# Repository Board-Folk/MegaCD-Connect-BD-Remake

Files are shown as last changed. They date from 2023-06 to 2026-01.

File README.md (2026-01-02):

# MegaCD-Connect-BD-Remake
This is the Schematics, PCB and Logic for the Mega-CD Connect BD Targeting the 315-5477 (MCE V1) MegaCD.

It is to replace the 837-8327-01 IC BD MEGA-CD CONNECT BD with a failed ASIC to the older Logic version of the board that has the Peel IC.

The board is not a clone, rather a remake as i do not have access to an original logic board version to do an exact replica of traces.

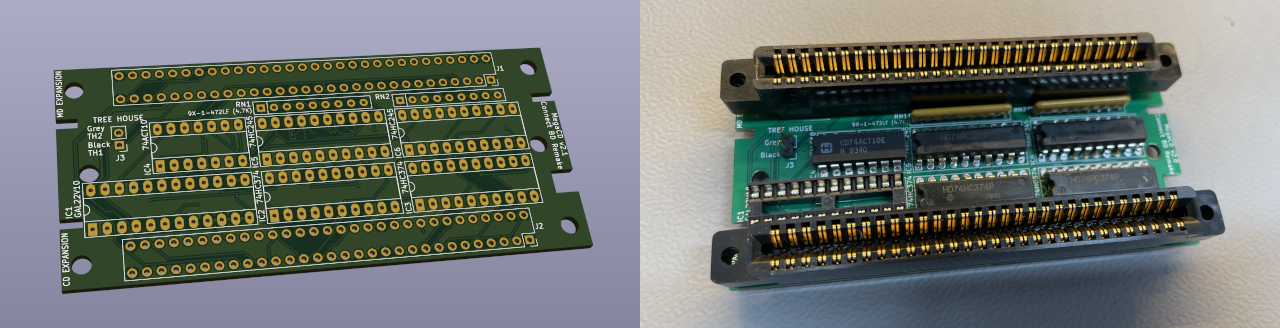
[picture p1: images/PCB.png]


* The Gerbers have been created using the recommendations from JLCPCB.

* This board uses a GAL22V10 to achieve the same logic functions as the Peel IC. Jed file is provided.
  Use a MiniPro to write the Jed file to the GAL Chip.

Notes:- 

 * I have used an ATF22V10B-15PC as a replacement for the GAL22V10. The ATF Works, but i also see this is obsolete. There is ATF22V10C range of chips, but stock seems to be low on these.

 * TESTED V2.0 and this worked, but now made V2.2 and is UNTESTED
   
 * Finally got some GAL20v8 Chips, and they do not work. Think this is a timing issue. So please use the GAL22v10's instead, unless someone wants to take a stab at getting the GAL20v8's to work. (Looks at Steve)

Version 2.3 Changes:-

Updates to Kicad v9, Changed A26/B26 on the CD Expansion to point to 9v, and not 5v. Made no difference with the older version, but made it now match the original PCB.

Added new Logic version, because GALasm was updated and was giving a different compiled version that does not work. Found what i needed to change to make it work.

You can use either Pre-Compiled Jed Files, for the GAL22v10 / ATF22V10

Version 2.2 Changes:-

* Moved traces around the middle screw holes, just incase screw heads sub against the silkscreen removing it and causing a short against the 5v rail.

* Moved the IC1 Silk name slightly up.

Version 2.1 Changes:-

* Moved /TRDIR from PIN 23 to PIN 15, This should make it compatible with the GAL20V8

* Added GAL20V8 Logic, but does not work.

* Updated Labels for Tree House Connection, TH1 and TH2

### Compiling The Logic
---

The software i used to make the Jed file was GALasm. It can be downloaded from here https://github.com/daveho/GALasm

Only source files is provide, so you will need to compile GALasm first. I used MacOS to do this, Linux should work and maybe Windows ???

Once GALasm is compiled, use the following command to compile the Logic into a Jed file from within the GAL22V10 folder.

```
galasm ./GAL22V10.pld
```

### Fitting the Board
---

**1. Post**

---

There is a slight modification required to make the PCB fit in the original housing.

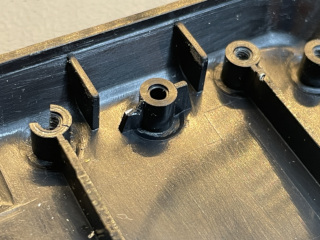
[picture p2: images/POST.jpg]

<br>This Post would need a little snip to allow the GAL chip pins to sit correctly in the housing.

**2. Tree House J3**

---

If you use a Pin Header, you will need to bend it slighly inwards otherwise it will not fit inside the MegaCD.

### BOM

---

| Reference | Value | Quantity | DigiKey | Mouser |
|---|---|---|---|---|
| C1 - C6 | 100nf | 6 | CL31B104KBCNNNC | 187-CL31B104KBCNNNC  |
| IC1 | GAL22V10B-15 / ATF22V10B-15 | 1 | | 556-AF22V10C15PU |
| IC2, IC3  | 74HC374 | 2 | 296-1592-5-ND | 595-SN74HC374N |
| IC4 | 74ACT10 | 1 | CD74ACT10E-ND | 595-CD74ACT10E |
| IC5, IC6  | 74HC245 | 2 | 296-1584-5-ND | 595-SN74HC245N |
| RN1, RN2  | 9X-1-472LF (4.7K) | 2 | 4609X-101-472LF-ND | 652-4609X-1LF-4.7K |
| J1, J2 | CONN EDGE DF 60POS | 2 | A112392-ND | 571-1-5530841-8 |
| J3 | 2 Pin Header 2.54mm | 1 | 609-4434-ND | 649-77311-118-02LF |

[**Interactive BOM**][IBOM]

## Thanks

With thanks to @fabiodl for decoding the logic of the Peel IC

* https://github.com/fabiodl/peelDecoder

#### Other Resources

* https://circuit-board.de/forum/index.php/Thread/25582-SEGA-MEGA-CD-1-Reparatur-PEEL-18CV8-PLD-auslesen/

* https://www.eevblog.com/forum/projects/help-with-reverse-engineering-unexpected-behavior-of-peel18cv8-223204/

### !!!!! WARNING !!!!!

Use at your own risk. I accept no responsibility.

[IBOM]: http://htmlpreview.github.io/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

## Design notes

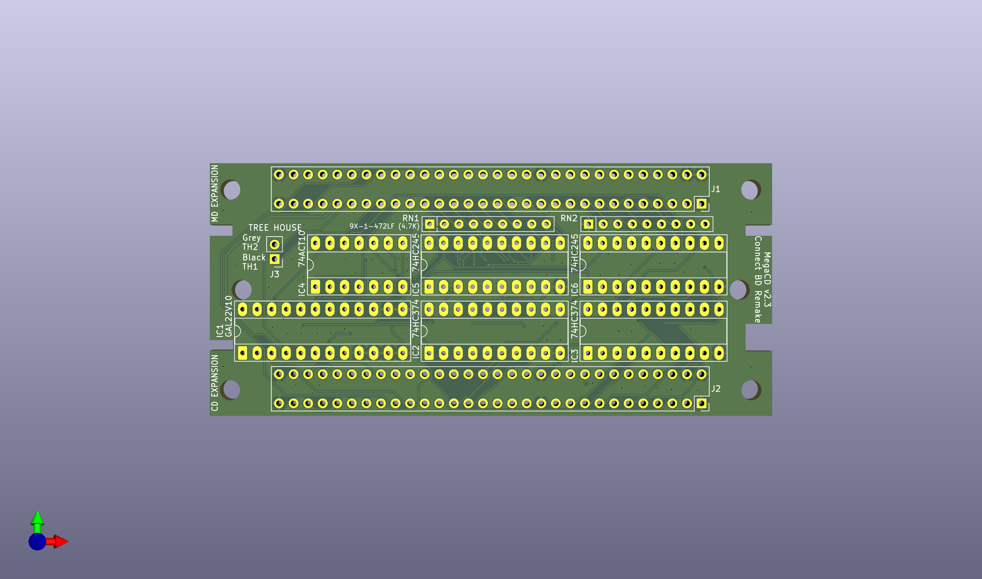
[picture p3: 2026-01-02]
MegaCD-Connect BD Remake.png

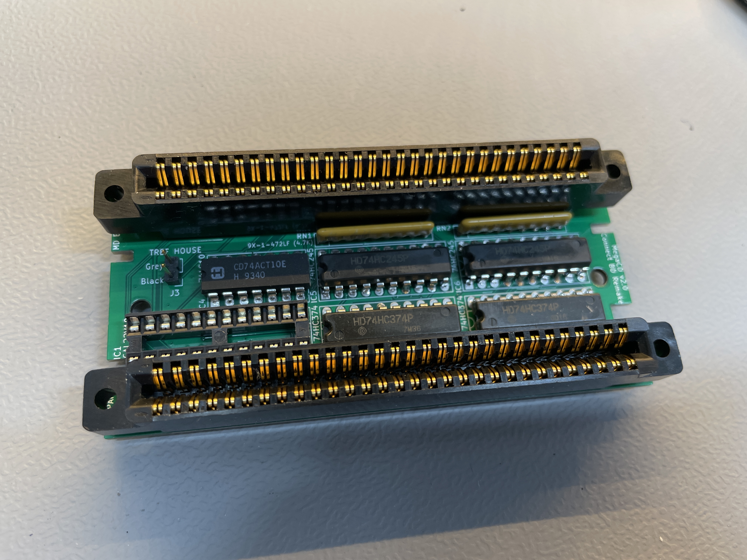
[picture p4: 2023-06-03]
images/MAIN.jpg

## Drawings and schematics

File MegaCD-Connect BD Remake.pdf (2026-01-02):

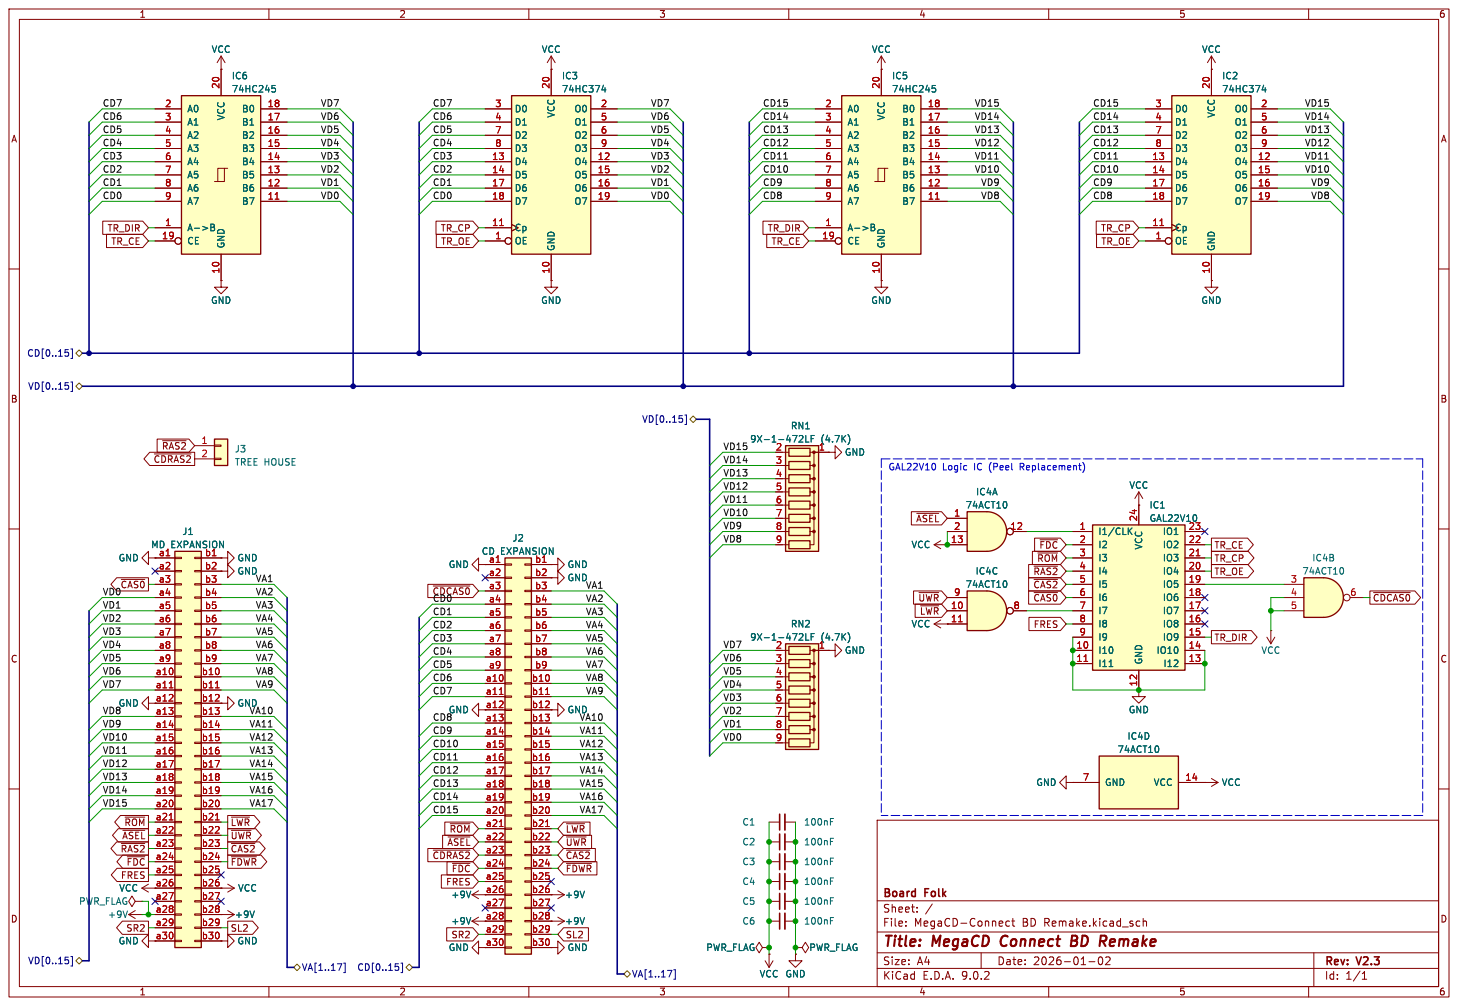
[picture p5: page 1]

Id: 1/1 Title: MegaCD Connect BD Remake

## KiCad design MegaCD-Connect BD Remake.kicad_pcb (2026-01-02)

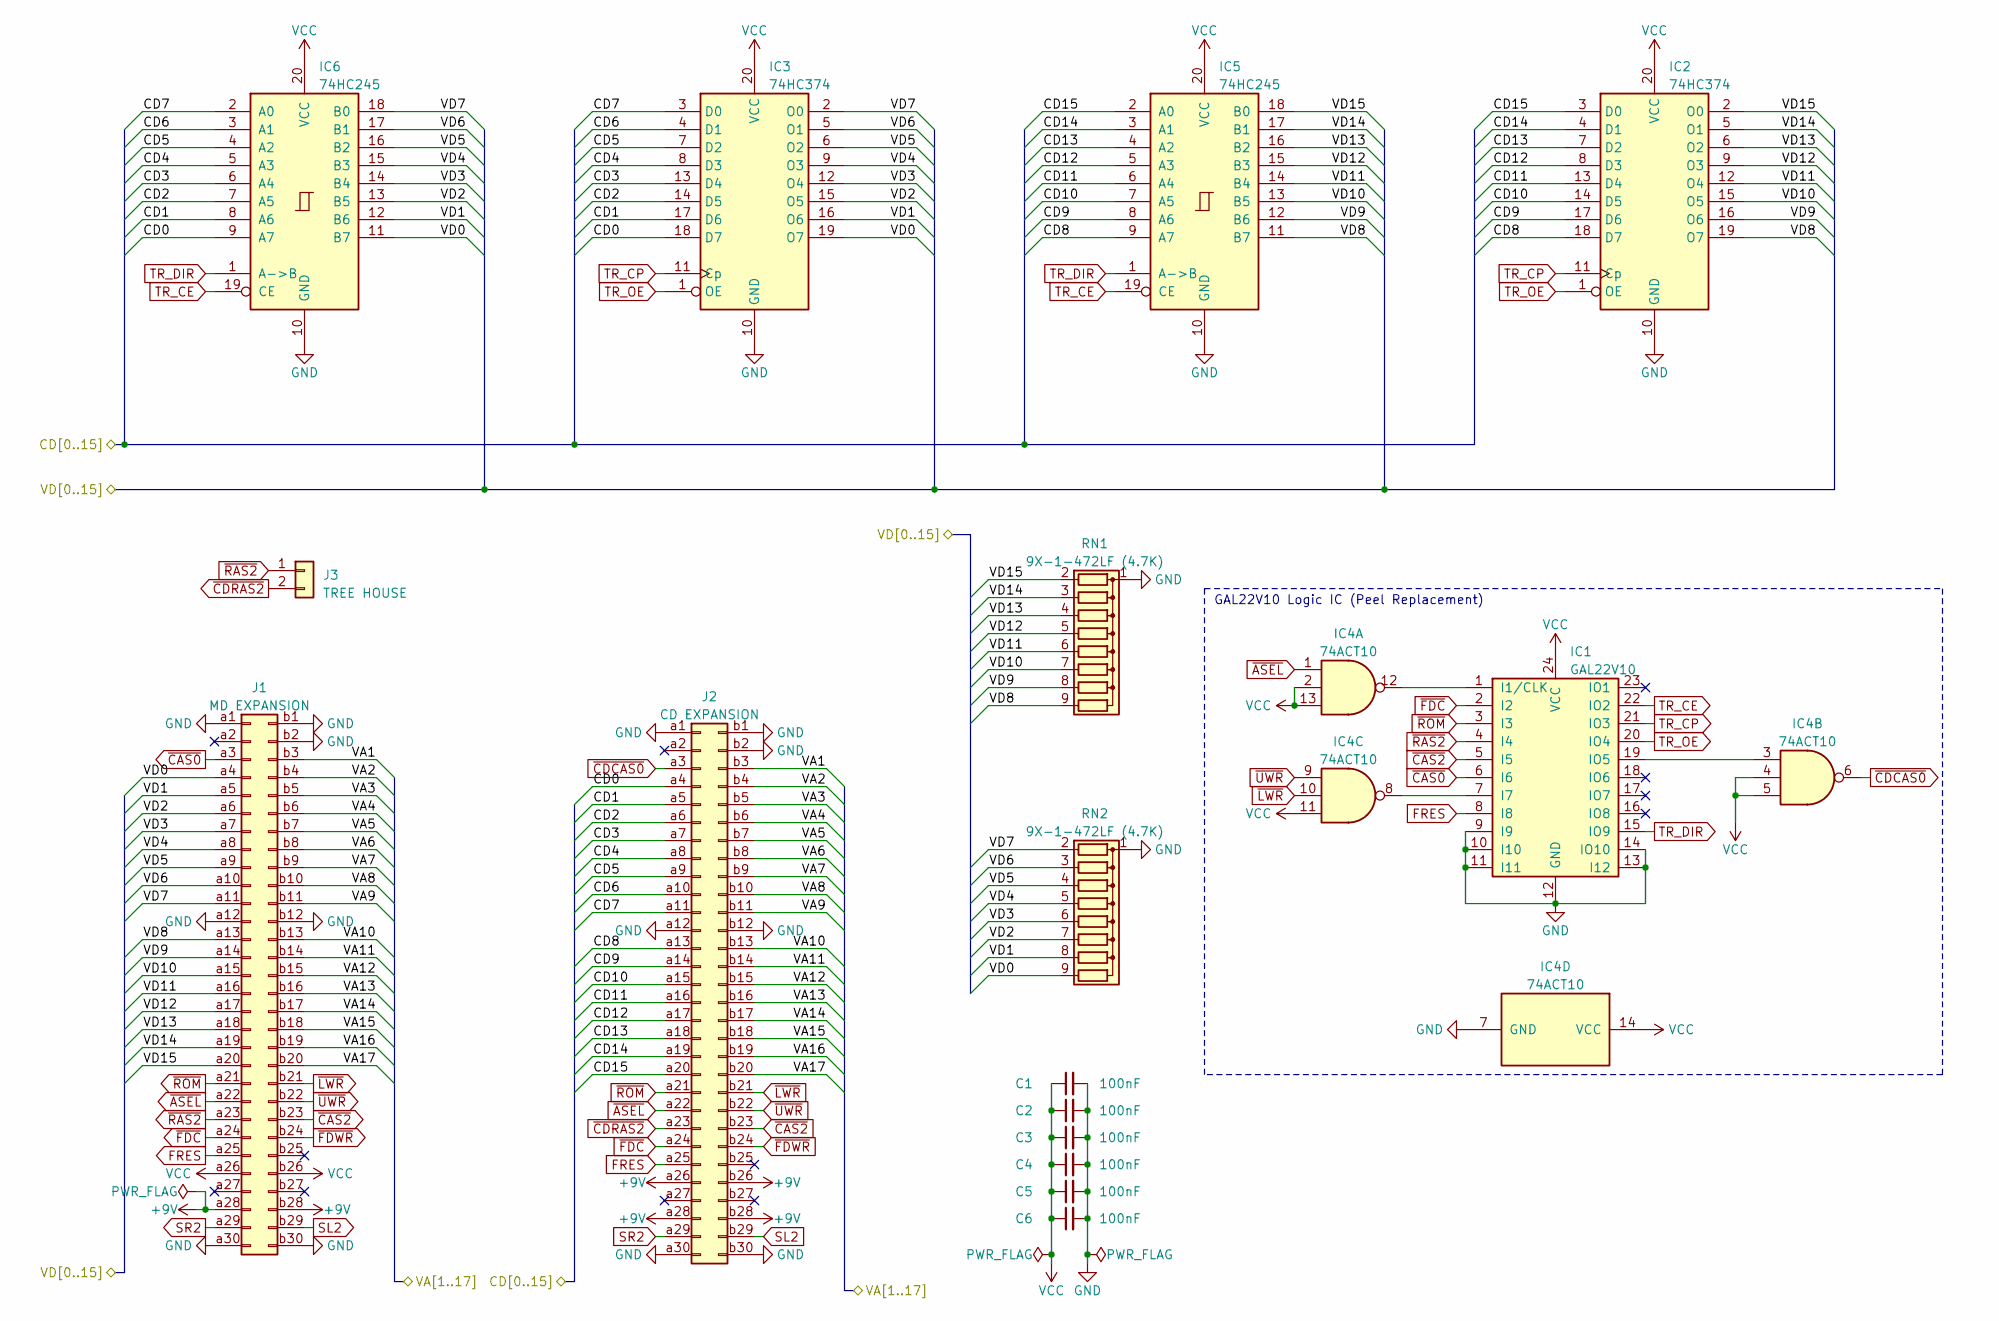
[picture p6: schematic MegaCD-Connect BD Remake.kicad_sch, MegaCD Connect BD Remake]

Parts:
C1, C2, C3, C4, C5, C6: 100nF; C_1206_3216Metric
IC1: GAL22V10; DIP-24_W7.62mm_Socket_LongPads
IC2, IC3: 74HC374; DIP-20_W7.62mm_Socket_LongPads
IC4: 74ACT10; DIP-14_W7.62mm_Socket_LongPads
IC5, IC6: 74HC245; DIP-20_W7.62mm_Socket_LongPads
J1: MD EXPANSION; PCB-Connector
J2: CD EXPANSION; PCB-Connector
J3: TREE HOUSE; PinHeader_1x02_P2.54mm_Vertical
RN1, RN2: 9X-1-472LF (4.7K); R_Array_SIP9

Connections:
+9V: J1.a28, J1.b28, J2.a26, J2.a28, J2.b26, J2.b28
/CD0: IC3.18 (D7), IC6.9 (A7), J2.a4
/CD1: IC3.17 (D6), IC6.8 (A6), J2.a5
/CD2: IC3.14 (D5), IC6.7 (A5), J2.a6
/CD3: IC3.13 (D4), IC6.6 (A4), J2.a7
/CD4: IC3.8 (D3), IC6.5 (A3), J2.a8
/CD5: IC3.7 (D2), IC6.4 (A2), J2.a9
/CD6: IC3.4 (D1), IC6.3 (A1), J2.a10
/CD7: IC3.3 (D0), IC6.2 (A0), J2.a11
/CD8: IC2.18 (D7), IC5.9 (A7), J2.a13
/CD9: IC2.17 (D6), IC5.8 (A6), J2.a14
/CD10: IC2.14 (D5), IC5.7 (A5), J2.a15
/CD11: IC2.13 (D4), IC5.6 (A4), J2.a16
/CD12: IC2.8 (D3), IC5.5 (A3), J2.a17
/CD13: IC2.7 (D2), IC5.4 (A2), J2.a18
/CD14: IC2.4 (D1), IC5.3 (A1), J2.a19
/CD15: IC2.3 (D0), IC5.2 (A0), J2.a20
/VA1: J1.b3, J2.b3
/VA2: J1.b4, J2.b4
/VA3: J1.b5, J2.b5
/VA4: J1.b6, J2.b6
/VA5: J1.b7, J2.b7
/VA6: J1.b8, J2.b8
/VA7: J1.b9, J2.b9
/VA8: J1.b10, J2.b10
/VA9: J1.b11, J2.b11
/VA10: J1.b13, J2.b13
/VA11: J1.b14, J2.b14
/VA12: J1.b15, J2.b15
/VA13: J1.b16, J2.b16
/VA14: J1.b17, J2.b17
/VA15: J1.b18, J2.b18
/VA16: J1.b19, J2.b19
/VA17: J1.b20, J2.b20
/VD0: IC3.19 (O7), IC6.11 (B7), J1.a4, RN2.9 (R8)
/VD1: IC3.16 (O6), IC6.12 (B6), J1.a5, RN2.8 (R7)
/VD2: IC3.15 (O5), IC6.13 (B5), J1.a6, RN2.7 (R6)
/VD3: IC3.12 (O4), IC6.14 (B4), J1.a7, RN2.6 (R5)
/VD4: IC3.9 (O3), IC6.15 (B3), J1.a8, RN2.5 (R4)
/VD5: IC3.6 (O2), IC6.16 (B2), J1.a9, RN2.4 (R3)
/VD6: IC3.5 (O1), IC6.17 (B1), J1.a10, RN2.3 (R2)
/VD7: IC3.2 (O0), IC6.18 (B0), J1.a11, RN2.2 (R1)
/VD8: IC2.19 (O7), IC5.11 (B7), J1.a13, RN1.9 (R8)
/VD9: IC2.16 (O6), IC5.12 (B6), J1.a14, RN1.8 (R7)
/VD10: IC2.15 (O5), IC5.13 (B5), J1.a15, RN1.7 (R6)
/VD11: IC2.12 (O4), IC5.14 (B4), J1.a16, RN1.6 (R5)
/VD12: IC2.9 (O3), IC5.15 (B3), J1.a17, RN1.5 (R4)
/VD13: IC2.6 (O2), IC5.16 (B2), J1.a18, RN1.4 (R3)
/VD14: IC2.5 (O1), IC5.17 (B1), J1.a19, RN1.3 (R2)
/VD15: IC2.2 (O0), IC5.18 (B0), J1.a20, RN1.2 (R1)
FRES: IC1.8 (I8), J1.a25, J2.a25
GND: C1.2, C2.2, C3.2, C4.2, C5.2, C6.2, IC1.9 (I9), IC1.10 (I10), IC1.11 (I11), IC1.12 (GND), IC1.13 (I12), IC1.14 (IO10), IC2.10 (GND), IC3.10 (GND), IC4.7 (GND), IC5.10 (GND), IC6.10 (GND), J1.a1, J1.a12, J1.a30, J1.b1, J1.b2, J1.b12, J1.b30, J2.a1, J2.a12, J2.a30, J2.b1, J2.b2, J2.b12, J2.b30, RN1.1 (common), RN2.1 (common)
unnamed: IC1.1 (I1/CLK), IC4.12
unnamed: IC1.7 (I7), IC4.8
unnamed: IC1.19 (IO5), IC4.3
SL2: J1.b29, J2.b29
SR2: J1.a29, J2.a29
TR_CE: IC1.22 (IO2), IC5.19 (CE), IC6.19 (CE)
TR_CP: IC1.21 (IO3), IC2.11 (Cp), IC3.11 (Cp)
TR_DIR: IC1.15 (IO9), IC5.1 (A->B), IC6.1 (A->B)
TR_OE: IC1.20 (IO4), IC2.1 (OE), IC3.1 (OE)
VCC: C1.1, C2.1, C3.1, C4.1, C5.1, C6.1, IC1.24 (VCC), IC2.20 (VCC), IC3.20 (VCC), IC4.2, IC4.4, IC4.5, IC4.11, IC4.13, IC4.14 (VCC), IC5.20 (VCC), IC6.20 (VCC), J1.a26, J1.b26
~ASEL: IC4.1, J1.a22, J2.a22
~CAS0: IC1.6 (I6), J1.a3
~CAS2: IC1.5 (I5), J1.b23, J2.b23
~CDCAS0: IC4.6, J2.a3
~CDRAS2: J2.a23, J3.2
~FDC: IC1.2 (I2), J1.a24, J2.a24
~FDWR: J1.b24, J2.b24
~LWR: IC4.10, J1.b21, J2.b21
~RAS2: IC1.4 (I4), J1.a23, J3.1
~ROM: IC1.3 (I3), J1.a21, J2.a21
~UWR: IC4.9, J1.b22, J2.b22

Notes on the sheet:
GAL22V10 Logic IC (Peel Replacement)

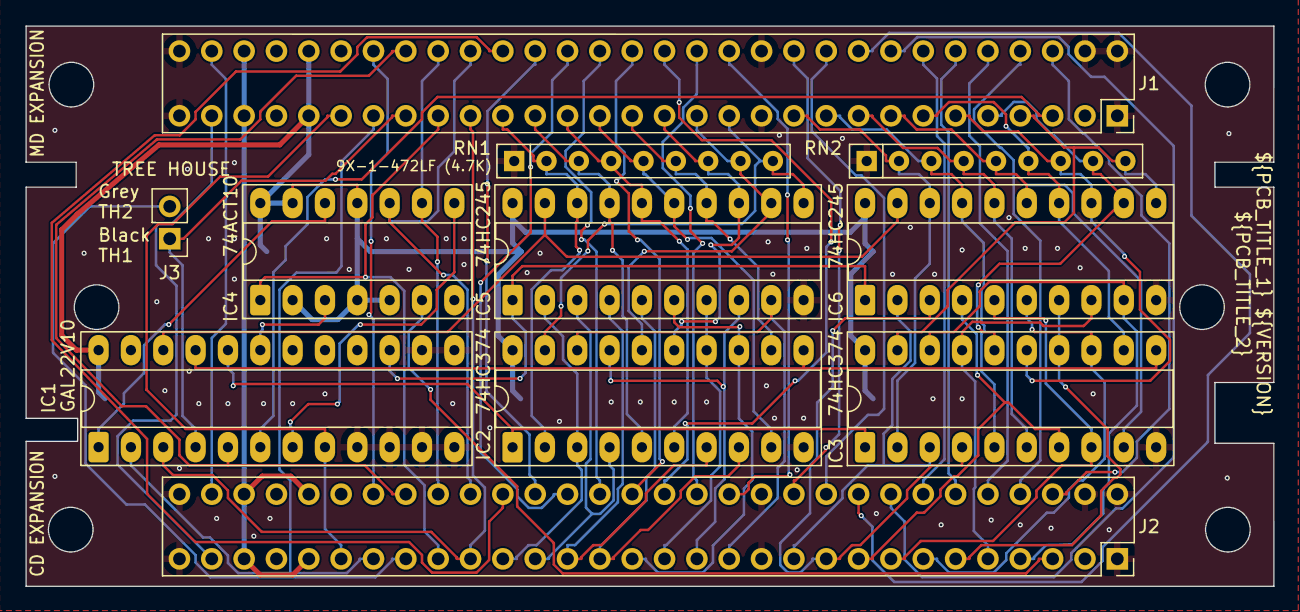
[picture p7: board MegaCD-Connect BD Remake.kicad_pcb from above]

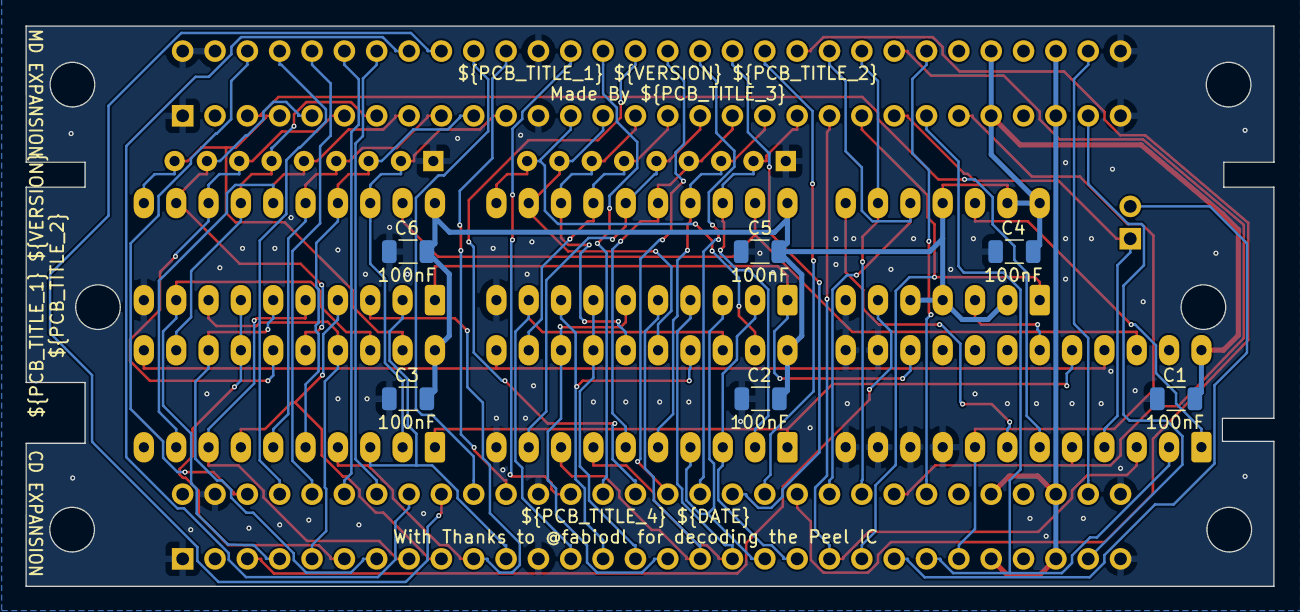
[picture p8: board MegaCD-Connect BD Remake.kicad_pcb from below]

Board: 2 copper layers, 98.0 x 44.0 mm, 17 parts (6 on the bottom side), 73 nets.

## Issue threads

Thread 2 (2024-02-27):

Issue programming the GAL

Parakas82, 2024-02-27:
Hi there,

Thanks for your projects, I am big fan! I am trying to reconstruct two JAP MCD1 units that had really bad PCBs, and they are coming back to life thanks to you.

Unfortunately I got stuck in the last bit, programming the GALs.
I got some (5X) GAL22V10B-15PC, and I am trying to program them with my T48 programmer, I load the JED file , and everything seems in order, but I get the following error when I try:

APP Version : 12.66   Model : T48
     Device : GAL22V10B
Pins Detected Passed!
Erase Chip....Timer : 828ms
Programing Fuse Bits completed ....Timer :4750 ms
Verify Error!    FUSE bit:0     Buff_val: 0     IC_val: 1
Programming Stopped!

And then I see that the GAL has only 1´s in it, so the process did nothing in the end.

I have tried different VPP voltages, enabling and disabling the ¨Encrypt Chip¨ flag, different IC models.... I run out of ideas to be honest. Apologies in advance if this is not the right place to ask something like this, I am not familiar using GitHub.
Thank you in advance for your time,

Regards.

chris-jh, 2024-02-27:
Where did you get the GAL's from ?

Parakas82, 2024-02-27:
Hi, Aliexpress 🙃 Got any good recommendation where should I source them at a reasonable price?

Thanks for the help!

chris-jh, 2024-02-27:
ah, yeah will be hit or miss with Ali, i had some that worked fine and others programmed no errors. But didn't worked.

Ones i got from eBay also worked, but probably same in getting genuine or fakes.

The mouser ATF22V10C-15PU as an alternative, at least with them should be real.

or try your luck on Ali/Ebay maybe they don't fake them as much ?? 😂

BBZ149, 2024-02-27:
Hi Chris, would pic of attached GAL work OK?

Thanks
Terry
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

chris-jh, 2024-02-28:
Looks ok, but looks can be deceiving😄, try it and see.

It will either programme and work, or programme and black screen, or not programme.

BBZ149, 2024-02-28:
That's true! lol but going by the model of the Chip is that the correct one? As I have to buy 15 and not cheap 😞 But they are 100% genuine!

chris-jh, 2024-02-29:
I am unsure i have only used the chips marked as GAL22V10B-15LP or ATF22V10B-15PC.

Parakas82, 2024-03-01:
Hi Chris,

Following your advice, I got some ATF22V10C-15PU on their way:
https://www.rs-online-privat.de/Products/ProductDetail/Microchip-SPLD-Simple-Programmable-Logic-Device-ATF22V10C-350-Gates-10-Makrozellen-10-I-O-83-3MHz-15ns-CMOS-TT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

Hopefully they will do the job, thanks for the help!

Regards.

chris-jh, 2024-03-24:
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

Did they work ?

Parakas82, 2024-03-24:
Hey Chris,

Experienced a bit of a nightmare with the delivery, but got them finally: they erased/programmed straight away. They are on their way to my colleague via post, to be tested with my two MCDs to be resurrected :) I'll let you know how it went.

Regards.

LobAnovich, 2024-03-26:
Greetings !  If using ATF22V10B-15PC, should I use the .jed firmware file from GAL22V10?

chris-jh, 2024-03-27:
yeah use the GAL22V10 jed as the ATF22V10B in the minipro if you are using that to program

Parakas82, 2024-03-30:
Confirmed, they work!!

LobAnovich, 2024-04-30:
Greetings !  I received 2 + 2 GAL22V10B chips from Ali from different sellers.  The chips are erased, programmed, but do not pass verification unless the “verification after recording” checkbox is unchecked.  Is it possible that this is a “lock bit” action and for the same reason it is impossible to remove a dump from the original chip or are these still fake chips?  Do I need to leave the “lock bit” and “encrypt chip” checkboxes before recording?  Programmer TL866II-Plus.  Xgpro 12.66 program

Closed 2024-03-30.

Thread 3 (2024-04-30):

GAL & ATF programming

LobAnovich, 2024-04-30:
Greetings !  I received 2 + 2 GAL22V10B chips from Ali from different sellers.  The chips are erased, programmed, but do not pass verification unless the “verification after recording” checkbox is unchecked.  Is it possible that this is a “lock bit” action and for the same reason it is impossible to remove a dump from the original chip or are these still fake chips?  Do I need to leave the “lock bit” and “encrypt chip” checkboxes before recording?  Programmer TL866II-Plus.  Xgpro 12.66 program

The situation with programming the ATF22V10C is slightly different.  The chips are erased, programmed, and verified at the end of the programming process, but if you try to re-verify separately, the verification is immediately loaded with exactly the same error as in the case of GAL during the programming process.  This gave me the idea that this situation arose due to the operation of the “lock bit”.  Or are all the chips faulty?

chris-jh, 2024-04-30:
Have you tried them yet?

I can't remember getting verification errors and i didnt mess with any lock bits or encryption.

years ago go i did use the gui version, but Mac is my main os and i use the open source minipro command line version now and i never specified them options.

If they dont work in the board, then i would assume fake or faulty.

unless it is the minipro you have ? an original or a clone ? i bought mine direct from xgecu

LobAnovich, 2024-04-30:
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

I have the original Xgecu TL866II-Plus programmer, which I have been using for many years.  I just identified a completely faulty batch of logic 74374 with his help, which I bought for assembling a riser board.  Lots 7410 and 74245 are fully operational

LobAnovich, 2024-04-30:
As I wrote earlier, the Chinese sent ATF22V10CQZ-20PC chips instead of ATF22V10B-15PC.  After several checks, I was able to write, count, and check a randomly selected chip, like ATF22V10C, several times, with a write voltage of 12 Volts and with the “lockbit” checkbox unchecked before writing

LobAnovich, 2024-05-05:
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

I restored my Sega mega cd addon and checked the adapter board clone.  I haven't tested it for a long time, so far it works fine

LobAnovich, 2024-12-14:
Also, all different ATF22V10B chips from different sellers, which were normally programmed and verified, do not work normally in sonic cd. The picture in the game itself, crumbles into squares, and then the game freezes. Only one version of GAL22V10B chips, from a large number that I bought from different sellers and which were normally flashed, has no problems in operation.

chris-jh, 2024-12-14:
What logic chips you are using ? i had issues with IC4 thinking it was something with the GAL Code. But it was that chip, which tested good in logic tests. But it was wrong/fake from the seller. Swapped that chip from ones i bought from mouser all good. it delayed this project a year. Shakes fists at fake chip sellers....

chris-jh, 2024-12-14:
Basically the Logic Chips needs to be the types specified on the BOM IC4 needs to be an ACT

LobAnovich, 2024-12-14:
ATF22V10B-15PC. ATF22V10CQZ-20PU
These are the chips that are flashed and verified normally. The project works with these chips, but the gameplay of the sonic cd does not work correctly.

LobAnovich, 2024-12-14:
Although... I reflashed the original IC4 with a multi-regional BIOS and there were much fewer artifacts with the ATF22V10B-15PC. I even managed to pass the first level. The second level started without any artifacts at all. It is quite possible that my ATF22V10B-15PC are actually relabeled from slower ATF22V10B-20,25 or even slower ones. As an experiment, I will try to find a faster chip for IC4 (-70 or -10). Finding a real working GAL22 or ATF22 is a very big problem.

LobAnovich, 2024-12-14:
> What logic chips you are using ? i had issues with IC4 thinking it was something with the GAL Code. But it was that chip, which tested good in logic tests. But it was wrong/fake from the seller. Swapped that chip from ones i bought from mouser all good. it delayed this project a year. Shakes fists at fake chip sellers....

What IC4 are you talking about? The logic chip on the connector board? I assumed that you were writing about the IC4 on the main board. And I replaced the BIOS chip with the original one reflashed with a multibios))) Although this also gave a result. A very positive result.
As for the IC4 on the connector board, I have 74HC10 installed, but there is also 74ACT10. Both versions pass tests on the programmer. I can also try replacing HC with ACT

chris-jh, 2024-12-14:
IC4 on the connect-bd board. I know the original peel board has all HC, and i can't remember why i put ACT in the box now. But i was getting lots of corruption and things, when this IC was not correct.

Other thing, did you put them caps back on the back of your board also ? Sega, being sega used to like adjusting timings by adding caps it seems. Was wondering if the boards you are trying are on this megacd that had them extra caps ?

chris-jh, 2024-12-14:
I bought the ATF22V10C15PU from mouser (556-AF22V10C15PU) they have plenty of stock and not EOL as far as i know. These are what i used.

Someone also pointed out to me that the ATF22V10 have a problem. The last fuse enables a "power down" mode on pin 4, and if it is erased it defaults to on. If you don't have a programmer that knows this you get odd behaviour when power down mode goes on.

LobAnovich, 2024-12-14:
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

I installed ceramic capacitors for regulation, like on the original board I had.

chris-jh, 2024-12-14:
wonder what happens with them removed between the resistor arrays.

Like i said, Sega when it sees issues with certain machines, they like to tweak data lines manually by adding random caps 😂

LobAnovich, 2024-12-14:
> wonder what happens with them removed between the resistor arrays.
>
> Like i said, Sega when it sees issues with certain machines, they like to tweak data lines manually by adding random caps 😂

I agree, but they do the adjustment manually not on each individual copy or even a separate batch, but on the entire batch, which was assembled from certain, identical components. That is, if, let's say, they started using any chip from another manufacturer and problems arise during testing, then they modify all copies in the same way.

LobAnovich, 2024-12-14:
I replaced the 74HC with a 74ACT and it got a little worse. I can still complete levels (the game doesn't freeze), but now the picture completely falls apart into squares, like it was today, before the BIOS chip was replaced, only then the game also froze at the beginning of the first level.

LobAnovich, 2024-12-15:
> I bought the ATF22V10C15PU from mouser (556-AF22V10C15PU) they have plenty of stock and not EOL as far as i know. These are what i used.
>
> Someone also pointed out to me that the ATF22V10 have a problem. The last fuse enables a "power down" mode on pin 4, and if it is erased it defaults to on. If you don't have a programmer that knows this you get odd behaviour when power down mode goes on.

Unfortunately, I only have access to chips from China, and even then they are mostly used and far from the full range.

The first time I flashed ATF.., using XGecu TL866II pro. The second time I flashed ATF... using XGecu T48. I don't know if these programmers know about the "power down fuse" or not. How should this "feature" manifest itself when the connection board with the ATF chip works...?

chris-jh, 2025-04-15:
Did you get this sorted ?

LobAnovich, 2025-04-15:
> Did you get this sorted ?

Yes, I bought some new GAL22V10B-10LP and some new AT27C1024-70PU (write-once). Now, with any testing, there are no problems in operation.

LobAnovich, 2025-04-15:
[MegaCD-Connect BD Remake_final.zip](https://github.com/user-attachments/files/19755773/MegaCD-Connect.BD.Remake_final.zip)

I also asked a friend to remake the source files for the production of the connection board, taking into account the change in the power lines and the installation of the capacitor. I ordered the production of boards according to these files, connection boards, but I have not yet checked the correctness.

LobAnovich, 2025-09-15:
> Is it possible to use some other Programmable Logic instead of GAL22V10B-15 / ATF22V10B-15

I am not the author of this project and have no information about the possibility of using other controllers. I tested only with GAL22 and ATF22

Sham-San, 2025-10-05:
> [MegaCD-Connect BD Remake_final.zip](https://github.com/user-attachments/files/19755773/MegaCD-Connect.BD.Remake_final.zip)
>
> I also asked a friend to remake the source files for the production of the connection board, taking into account the change in the power lines and the installation of the capacitor. I ordered the production of boards according to these files, connection boards, but I have not yet checked the correctness.

What is the capacitance of C7?
C1-C6 is 0.1 μF?

LobAnovich, 2025-10-07:
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

C1-C6 (0.1 µF).  C7 (47-100 uF)

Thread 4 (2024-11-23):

Correctness of transfer of power lines

LobAnovich, 2024-11-23:
It may not affect the operation, but you need to double-check the correctness of the transfer of the 5 volt (A26, B26) and 9 volt (A28, B28) power lines that control the addon. In the original, the input 5 volts (A26, B26) only power the chips of the transition board. The output contacts A26, B26 are not connected to the input contacts A26, B26 (5 volts), but are connected to the input contacts A28, B28 (9 volts)

chris-jh, 2025-04-15:
I will correct when i get around to doing a proper peel board clone of the board.

Talking with Leo, it isn't connected on the MegaCD, probably why i didn't notice as nothing went boom. Will leave it open as a reminder.

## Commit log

2023-05-14 Initial Commit
    Initial Commit
    [MegaCD-Connect BD Remake-B_Cu.gbl, MegaCD-Connect BD Remake-B_Mask.gbs, MegaCD-Connect BD Remake-B_Paste.gbp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]
2023-06-03 Update PCB to Version 2.1 * Moved /TRDIR from pin 23 to pin 15 * Added GAL20V8 Logic * Updated Labels for Tree House Connection, TH1 and TH2 * Added an iBom * Updated the ReadMe
    [MegaCD-Connect BD Remake-B_Cu.gbl, MegaCD-Connect BD Remake-B_Mask.gbs, MegaCD-Connect BD Remake-B_Paste.gbp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]
2023-06-13 Updated to v2.2
    Moved traces near the two middle screws.
    [MegaCD-Connect BD Remake-B_Cu.gbl, MegaCD-Connect BD Remake-B_Mask.gbs, MegaCD-Connect BD Remake-B_Paste.gbp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]
2023-09-29 Update README.md
    Update BOM
2026-01-02 Updated PCB to v2.3 removed A26 B26 Linking to VCC and back to 9V instead on the CD Side Only.
    [MegaCD-Connect BD Remake-B_Cu.gbl, MegaCD-Connect BD Remake-B_Mask.gbs, MegaCD-Connect BD Remake-B_Paste.gbp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]
